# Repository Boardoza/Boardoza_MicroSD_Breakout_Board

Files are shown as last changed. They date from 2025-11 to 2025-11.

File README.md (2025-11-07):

# Boardoza MicroSD Breakout Board

The **Boardoza MicroSD Breakout Board** is a compact storage solution that enables microSD card interfacing via **SPI communication protocol**. This breakout board features an integrated **voltage regulator** that converts 5V input to 3.3V operation, ensuring safe and reliable communication with microSD cards while maintaining compatibility with both 3.3V and 5V microcontroller systems.

With its small form factor of **20mm x 40mm**, this module provides an easy way to add mass storage capabilities to embedded projects, data logging applications, and IoT devices. The board is optimized for high-speed data transfer and features **3.3V tolerant SPI pins** for seamless integration.

## [Click here to purchase!](https://www.ozdisan.com/p/gelistirme-kitleri-ve-aksesuarlari-617/boardoza-boardoza-microsd-1202712)

|Front Side|Back Side|
|:---:|:---:|
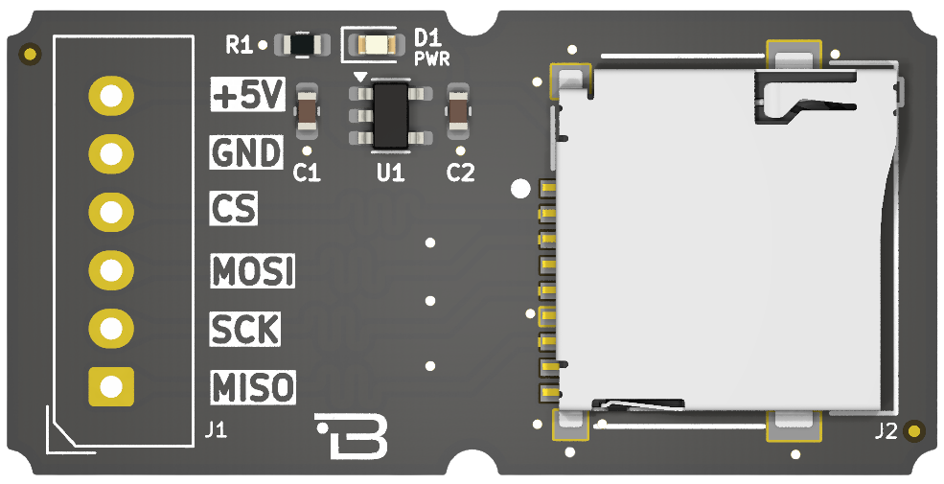
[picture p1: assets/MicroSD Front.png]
MicroSD Front
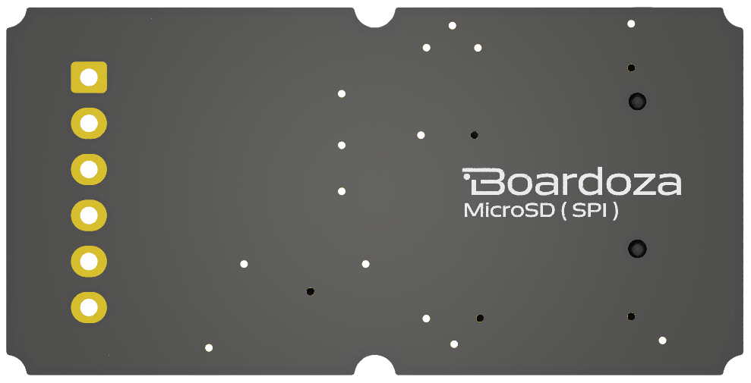
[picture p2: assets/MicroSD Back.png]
MicroSD Back
| | |

---

## Key Features

- **SPI Communication Interface:** Standard SPI protocol for universal microcontroller compatibility.
- **Integrated Voltage Regulation:** Converts 5V input to 3.3V operation for safe microSD card interfacing.
- **3.3V Tolerant I/O:** All SPI pins are 3.3V tolerant, protecting the microSD card from overvoltage.
- **High-Speed Data Transfer:** Optimized for fast read/write operations with microSD cards.
- **Compact Design:** Small 20mm x 40mm form factor for space-constrained applications.
- **Wide Compatibility:** Works with microSD and microSDHC cards up to 32GB.
- **Simple Integration:** Standard SPI pinout for easy connection to Arduino, ESP32, STM32, and other platforms.

---

## Technical Specifications

**Input Voltage:** 5V  
**Voltage Input Type:** 6-pin 2.50mm header  
**Operating Voltage:** 3.3V (regulated)  
**Interface:** SPI (Serial Peripheral Interface)  
**Functions:** MicroSD Card Reader/Writer Module  
**I/O Voltage Level:** 3.3V tolerant  
**Supported Cards:** MicroSD, MicroSDHC (up to 32GB)  
**Operating Temperature:** -40°C ~ +85°C  
**Board Dimensions:** 20mm x 40mm

---

## Board Pinout

### **( J1 ) SPI Communication Pins**

| Pin Number | Pin Name | Description |
|:---:|:---:|---|
| 1 | MISO | Master Input Slave Output (3.3V tolerant) |
| 2 | SCK | Serial Clock (3.3V tolerant) |
| 3 | MOSI | Master Output Slave Input (3.3V tolerant) |
| 4 | CS | Chip Select (3.3V tolerant) |
| 5 | GND | Ground (0V reference) |
| 6 | +5V | Positive voltage input |

---

## Board Dimensions

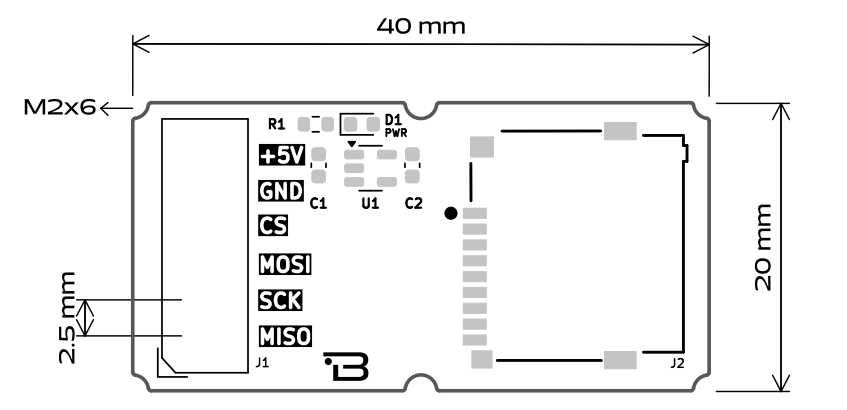
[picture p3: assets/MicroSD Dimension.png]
MicroSD Breakout Dimensions


---

## Step Files

[Boardoza MicroSD.step](./assets/MicroSD%20Step.step)

---

## Datasheet

[MicroSD Breakout Board Datasheet.pdf](./assets/MicroSD%20Datasheet.pdf)

---

## Version History

- V1.0.0 - Initial Release

---

## Support

- If you have any questions or need support, please contact <support@boardoza.com>

---

## License

Shield: [][cc-by-sa]

This work is licensed under a [Creative Commons Attribution-ShareAlike 4.0 International License][cc-by-sa].

[][cc-by-sa]

[cc-by-sa]: http://creativecommons.org/licenses/by-sa/4.0/
[cc-by-sa-image]: https://licensebuttons.net/l/by-sa/4.0/88x31.png
[cc-by-sa-shield]: https://img.shields.io/badge/License-CC%20BY--SA%204.0-lightgrey.svg

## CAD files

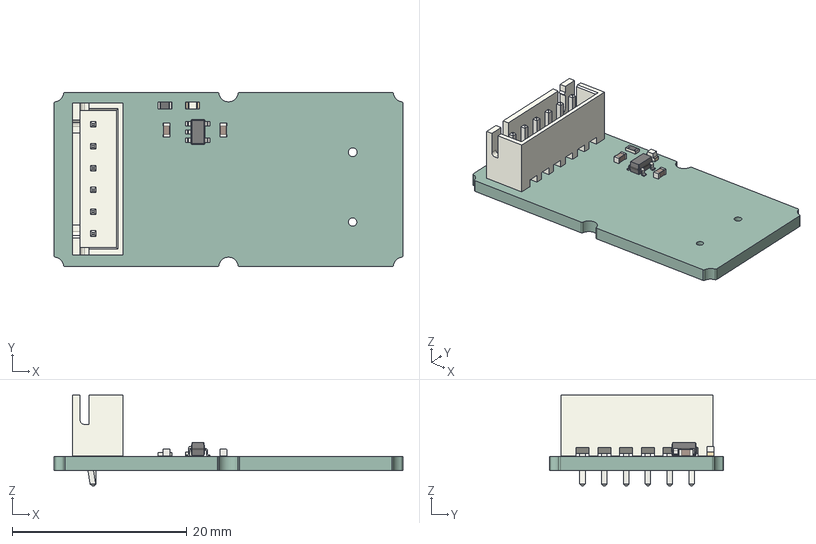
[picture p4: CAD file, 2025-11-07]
assets/MicroSD Step.step
40.0 x 20.0 x 10.4 mm
C_0603_1608Metric x 2
LED_0603_1608Metric
R_0603_1608Metric
JST_B6B_XH_A
SOT_23_5
B-MicroSD-BRK-01MBR-R01_PCB

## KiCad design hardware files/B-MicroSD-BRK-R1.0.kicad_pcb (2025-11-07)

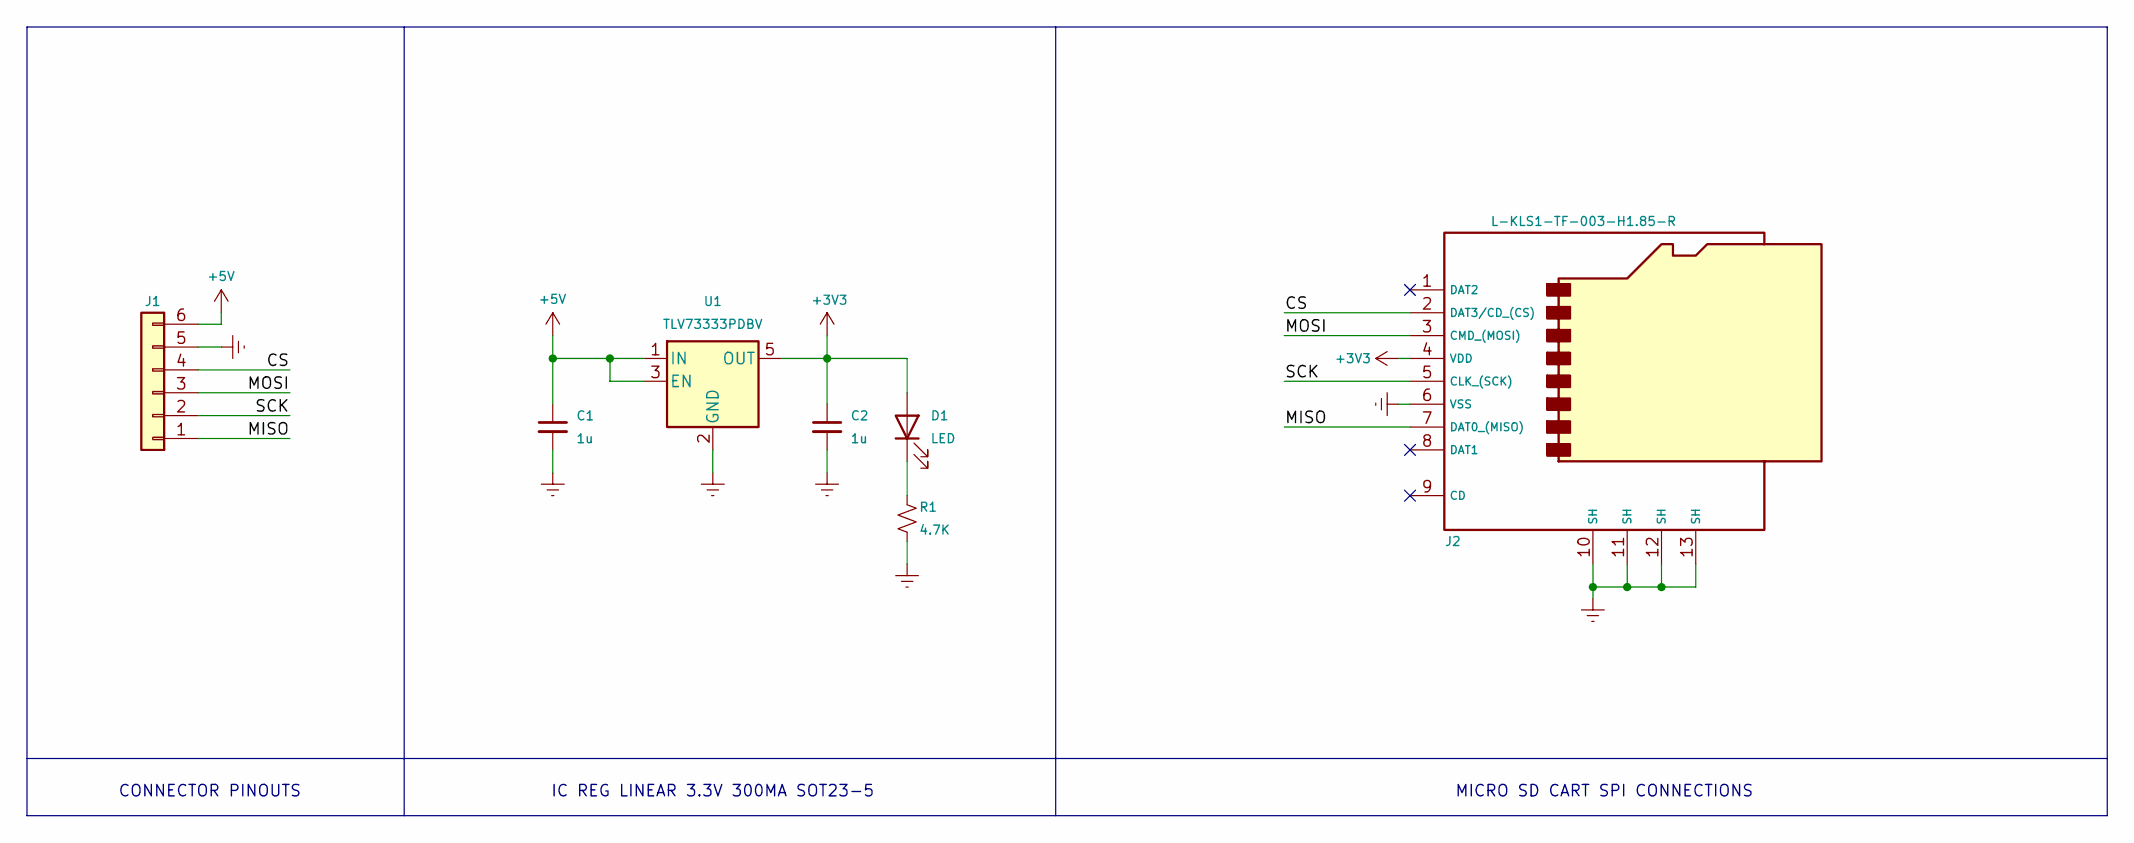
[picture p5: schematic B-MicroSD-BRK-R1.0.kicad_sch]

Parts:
C1, C2: 1u; C_0603_1608Metric; MPN CL10B105KA8NNNC
D1: LED; LED_0603_1608Metric; MPN LTST-C190KRKT
J1: Conn_01x06; 2317-06S_1x06_P2.50mm_Vertical; MPN 2317-06S
J2: L-KLS1-TF-003-H1.85-R; MPN L-KLS1-TF-003-H1.85-R
R1: 4.7K; R_0603_1608Metric; MPN 0603SAJ0472T5E
U1: TLV73333PDBV; SOT-23-5; MPN TLV73333PDBVR

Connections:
+3V3: C2.1, D1.2 (A), J2.4 (VDD), U1.5 (OUT)
+5V: C1.1, J1.6, U1.1 (IN), U1.3 (EN)
/CS: J1.4, J2.2 (DAT3/CD_(CS))
/MISO: J1.1, J2.7 (DAT0_(MISO))
/MOSI: J1.3, J2.3 (CMD_(MOSI))
/SCK: J1.2, J2.5 (CLK_(SCK))
Earth: C1.2, C2.2, J1.5, J2.6 (VSS), J2.10 (SH), J2.11 (SH), J2.12 (SH), J2.13 (SH), R1.2, U1.2 (GND)
unnamed: D1.1 (K), R1.1

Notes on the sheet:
CONNECTOR PINOUTS
IC REG LINEAR 3.3V 300MA SOT23-5
MICRO SD CART SPI CONNECTIONS

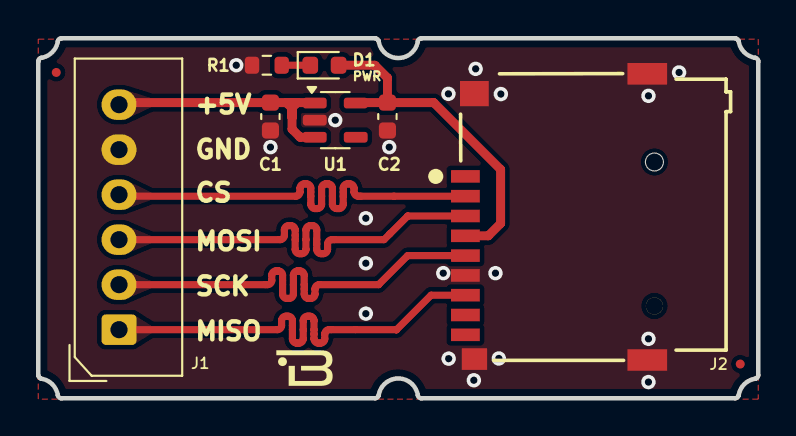
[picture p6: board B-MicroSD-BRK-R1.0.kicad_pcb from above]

Board: 2 copper layers, 40.0 x 20.0 mm, 7 parts (0 on the bottom side), 8 nets.

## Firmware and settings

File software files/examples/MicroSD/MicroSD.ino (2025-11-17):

/*
 * This program attempts to initialize an SD card and analyze its structure.
 */
#include "Arduino.h"
#include "SdFat.h"
#include "sdios.h"
/*
  Set DISABLE_CS_PIN to disable a second SPI device.
  For example, with the Ethernet shield, set DISABLE_CS_PIN
  to 10 to disable the Ethernet controller.
*/
const int8_t DISABLE_CS_PIN = -1;
/*
  Change the value of SD_CS_PIN if you are using SPI
  and your hardware does not use the default value, SS.
  Common values are:
  Arduino Ethernet shield: pin 4
  Sparkfun SD shield: pin 8
  Adafruit SD shields and modules: pin 10
*/
// SDCARD_SS_PIN is defined for the built-in SD on some boards.
#ifndef SDCARD_SS_PIN
const uint8_t SD_CS_PIN = 5;
#else  // SDCARD_SS_PIN
const uint8_t SD_CS_PIN = SDCARD_SS_PIN;
#endif  // SDCARD_SS_PIN

// Try to select the best SD card configuration.
#if HAS_SDIO_CLASS
#define SD_CONFIG SdioConfig(FIFO_SDIO)
#elif ENABLE_DEDICATED_SPI
#define SD_CONFIG SdSpiConfig(SD_CS_PIN, DEDICATED_SPI, SD_SCK_MHZ(16))
#else  // HAS_SDIO_CLASS
#define SD_CONFIG SdSpiConfig(SD_CS_PIN, SHARED_SPI, SD_SCK_MHZ(16))
#endif  // HAS_SDIO_CLASS

//------------------------------------------------------------------------------
SdFs sd;
cid_t cid;
csd_t csd;
scr_t scr;
uint8_t cmd6Data[64];
uint32_t eraseSize;
uint32_t ocr;
static ArduinoOutStream cout(Serial);
//------------------------------------------------------------------------------
void cidDmp() {
  cout << F("\nManufacturer ID: ");
  cout << uppercase << showbase << hex << int(cid.mid) << dec << endl;
  cout << F("OEM ID: ") << cid.oid[0] << cid.oid[1] << endl;
  cout << F("Product: ");
  for (uint8_t i = 0; i < 5; i++) {
    cout << cid.pnm[i];
  }
  cout << F("\nRevision: ") << cid.prvN() << '.' << cid.prvM() << endl;
  cout << F("Serial number: ") << hex << cid.psn() << dec << endl;
  cout << F("Manufacturing date: ");
  cout << cid.mdtMonth() << '/' << cid.mdtYear() << endl;
  cout << endl;
}
//------------------------------------------------------------------------------
void clearSerialInput() {
  uint32_t m = micros();
  do {
    if (Serial.read() >= 0) {
      m = micros();
    }
  } while (micros() - m < 10000);
}
//------------------------------------------------------------------------------
void csdDmp() {
  eraseSize = csd.eraseSize();
  cout << F("cardSize: ") << 0.000512 * csd.capacity();
  cout << F(" MB (MB = 1,000,000 bytes)\n");

  cout << F("flashEraseSize: ") << int(eraseSize) << F(" blocks\n");
  cout << F("eraseSingleBlock: ");
  if (csd.eraseSingleBlock()) {
    cout << F("true\n");
  } else {
    cout << F("false\n");
  }
  cout << F("dataAfterErase: ");
  if (scr.dataAfterErase()) {
    cout << F("ones\n");
  } else {
    cout << F("zeros\n");
  }
}
//------------------------------------------------------------------------------
void errorPrint() {
  if (sd.sdErrorCode()) {
    cout << F("SD errorCode: ") << hex << showbase;
    printSdErrorSymbol(&Serial, sd.sdErrorCode());
    cout << F(" = ") << int(sd.sdErrorCode()) << endl;
    cout << F("SD errorData = ") << int(sd.sdErrorData()) << dec << endl;
  }
}
//------------------------------------------------------------------------------
bool mbrDmp() {
  MbrSector_t mbr;
  bool valid = true;
  if (!sd.card()->readSector(0, (uint8_t*)&mbr)) {
    cout << F("\nread MBR failed.\n");
    errorPrint();
    return false;
  }
  cout << F("\nSD Partition Table\n");
  cout << F("part,boot,bgnCHS[3],type,endCHS[3],start,length\n");
  for (uint8_t ip = 1; ip < 5; ip++) {
    MbrPart_t *pt = &mbr.part[ip - 1];
    if ((pt->boot != 0 && pt->boot != 0X80) ||
        getLe32(pt->relativeSectors) > csd.capacity()) {
      valid = false;
    }
    cout << int(ip) << ',' << uppercase << showbase << hex;
    cout << int(pt->boot) << ',';
    for (int i = 0; i < 3; i++ ) {
      cout << int(pt->beginCHS[i]) << ',';
    }
    cout << int(pt->type) << ',';
    for (int i = 0; i < 3; i++ ) {
      cout << int(pt->endCHS[i]) << ',';
    }
    cout << dec << getLe32(pt->relativeSectors) << ',';
    cout << getLe32(pt->totalSectors) << endl;
  }
  if (!valid) {
    cout << F("\nMBR not valid, assuming Super Floppy format.\n");
  }
  return true;
}
//------------------------------------------------------------------------------
void dmpVol() {
  cout << F("\nScanning FAT, please wait.\n");
  int32_t freeClusterCount = sd.freeClusterCount();
  if (sd.fatType() <= 32) {
    cout << F("\nVolume is FAT") << int(sd.fatType()) << endl;
  } else {
    cout << F("\nVolume is exFAT\n");
  }
  cout << F("sectorsPerCluster: ") << sd.sectorsPerCluster() << endl;
  cout << F("fatStartSector:    ") << sd.fatStartSector() << endl;
  cout << F("dataStartSector:   ") << sd.dataStartSector() << endl;
  cout << F("clusterCount:      ") << sd.clusterCount() << endl;  
  cout << F("freeClusterCount:  ");
  if (freeClusterCount >= 0) {
    cout << freeClusterCount << endl;
  } else {
    cout << F("failed\n");
    errorPrint();    
  }
}
//------------------------------------------------------------------------------
void printCardType() {

  cout << F("\nCard type: ");

  switch (sd.card()->type()) {
    case SD_CARD_TYPE_SD1:
      cout << F("SD1\n");
      break;

    case SD_CARD_TYPE_SD2:
      cout << F("SD2\n");
      break;

    case SD_CARD_TYPE_SDHC:
      if (csd.capacity() < 70000000) {
        cout << F("SDHC\n");
      } else {
        cout << F("SDXC\n");
      }
      break;

    default:
      cout << F("Unknown\n");
  }
}
//------------------------------------------------------------------------------
void printConfig(SdSpiConfig config) {
  if (DISABLE_CS_PIN < 0) {
    cout << F(
           "\nAssuming the SD is the only SPI device.\n"
           "Edit DISABLE_CS_PIN to disable an SPI device.\n");
  } else {
    cout << F("\nDisabling SPI device on pin ");
    cout << int(DISABLE_CS_PIN) << endl;
    pinMode(DISABLE_CS_PIN, OUTPUT);
    digitalWrite(DISABLE_CS_PIN, HIGH);
  }
  cout << F("\nAssuming the SD chip select pin is: ") << int(config.csPin);
  cout << F("\nEdit SD_CS_PIN to change the SD chip select pin.\n");
}
//------------------------------------------------------------------------------
void printConfig(SdioConfig config) {
  (void)config;
  cout << F("Assuming an SDIO interface.\n");
}
//-----------------------------------------------------------------------------
void setup() {
  Serial.begin(115200);
  // Wait for USB Serial
  while (!Serial) {
    yield();
  }
  cout << F("SdFat version: ") << SD_FAT_VERSION_STR << endl;
  printConfig(SD_CONFIG);

}
//------------------------------------------------------------------------------
void loop() {
  // Read any existing Serial data.
  clearSerialInput();

  // F stores strings in flash to save RAM
  cout << F("\ntype any character to start\n");
  while (!Serial.available()) {
    yield();
  }
  uint32_t t = millis();
  if (!sd.cardBegin(SD_CONFIG)) {
    cout << F(
           "\nSD initialization failed.\n"
           "Do not reformat the card!\n"
           "Is the card correctly inserted?\n"
           "Is there a wiring/soldering problem?\n");
    if (isSpi(SD_CONFIG)) {
      cout << F(
           "Is SD_CS_PIN set to the correct value?\n"
           "Does another SPI device need to be disabled?\n"
           );
    }
    errorPrint();
    return;
  }
  t = millis() - t;
  cout << F("init time: ") << dec << t << " ms" << endl;

  if (!sd.card()->readCID(&cid) ||
      !sd.card()->readCSD(&csd) ||
      !sd.card()->readOCR(&ocr) ||
      !sd.card()->readSCR(&scr)) {
    cout << F("readInfo failed\n");
    errorPrint();
    return;
  }
  printCardType();
  cout << F("sdSpecVer: ") << 0.01*scr.sdSpecVer() << endl;
  cout << F("HighSpeedMode: ");
  if (scr.sdSpecVer() &&
    sd.card()->cardCMD6(0X00FFFFFF, cmd6Data) && (2 & cmd6Data[13])) {
    cout << F("true\n");
  } else {
    cout << F("false\n");
  }      
  cidDmp();
  csdDmp();
  cout << F("\nOCR: ") << uppercase << showbase;
  cout << hex << ocr << dec << endl;
  if (!mbrDmp()) {
    return;
  }
  if (!sd.volumeBegin()) {
    cout << F("\nvolumeBegin failed. Is the card formatted?\n");
    errorPrint();
    return;
  }
  dmpVol();
}
